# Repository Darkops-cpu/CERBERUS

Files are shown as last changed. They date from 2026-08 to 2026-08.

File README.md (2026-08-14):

# Cerberus

An open-source iCE40 FPGA development board with a fully open toolchain.

No licence server, no 100 GB install. Yosys, nextpnr and IceStorm run on any laptop and
synthesise a design this size in seconds.

> **Status:** rev A, first boards in fabrication. Untested. Do not fabricate your own copy
> until this note is gone.

---

## Features

| | |
|---|---|
| **FPGA** | Lattice iCE40UP5K — 5,280 LUT4, 120 kbit BRAM, 1 Mbit SPRAM, 8 DSP blocks |
| **PSRAM** | 8 MB QSPI (LY68L6400SLIT) |
| **Flash** | 4 MB SPI configuration flash (W25Q32) |
| **Host** | FT2232HL — USB programming *and* a serial console over one cable |
| **Clock** | 12 MHz active oscillator into a global clock buffer |
| **Expansion** | 2× PMOD, 8 user GPIO on a 0.1" header |
| **LEDs** | 3 user RGB + power, USB and CDONE status |
| **Connector** | USB-C |
| **PCB** | 4-layer, hand-assembled |

The FT2232H's two channels run independently, so you can flash a bitstream and watch a UART
console at the same time without switching modes.

---

## Getting started

### 1. Install the toolchain

Download the [OSS CAD Suite](https://github.com/YosysHQ/oss-cad-suite-build/releases) and
add it to your `PATH`. That's Yosys, nextpnr, IceStorm, Icarus, Verilator, GTKWave and
`iceprog` in one archive. Nothing to compile, nothing to licence.

```sh
source <path-to-oss-cad-suite>/environment
```

### 2. Build

```sh
yosys -p 'synth_ice40 -top top -json top.json' top.v
nextpnr-ice40 --up5k --package sg48 --json top.json --pcf cerberus.pcf --asc top.asc
icepack top.asc top.bin
```

### 3. Flash

The config SPI is on the FT2232H's **channel B**, so the `-I B` flag is required:

```sh
iceprog -I B top.bin
```

The CDONE LED lights when configuration succeeds.

### 4. Console

Channel A enumerates as a second serial port. On Linux the two channels appear as
`/dev/ttyUSB0` (A) and `/dev/ttyUSB1` (B):

```sh
picocom -b 115200 /dev/ttyUSB0
```

---

## Pinout

Key pins. Everything else is in `cerberus.pcf`.

| Function | FPGA pin |
|---|---|
| 12 MHz clock in | 37 (G1) |
| UART TX (FPGA → host) | 18 |
| UART RX (host → FPGA) | 19 |
| PSRAM CE# | 6 |
| PSRAM SCK | 9 |
| PSRAM SIO0–3 | 10, 11, 12, 13 |
| RGB LEDs | 39, 40, 41 |
| CDONE | 7 |
| CRESET_B | 8 |

Pins 14–17 are the configuration SPI bus and are not available to user designs.

**Globals available on this package:** 35 (G0), 37 (G1), 20 (G3), 44 (G6). Put clocks on
these — a clock on an ordinary pin routes through general fabric with worse skew.

**RGB LEDs** are constant-current sinks driven by the `SB_RGBA_DRV` primitive. Current is
set in the IP, not by a resistor.

---

## Notes

**Reset.** The button pulls `CRESET_B` low and reconfigures the FPGA from flash on release.
Configuration takes under 140 ms.

**Internal oscillator.** The iCE40's internal 48 MHz `SB_HFOSC` is ±20% on industrial parts.
Fine for blinking an LED, useless for a UART — that's why the board has an external
oscillator. Use pin 37.

**PSRAM.** The controller must break long transfers into chunks and deassert CE# between
them — the part self-refreshes only while CE# is high, and holding it low past the tCEM
window loses data. Linear burst across page boundaries is not supported on this part.

**Powering.** Bus-powered from USB-C. There is no barrel jack and no external supply input.

---

## Licence

Hardware: [CERN-OHL-S v2](https://cern-ohl.web.cern.ch/)
Gateware and examples: MIT

---

## Acknowledgements

Built on the work of [YosysHQ](https://github.com/YosysHQ) and
[Project IceStorm](https://github.com/YosysHQ/icestorm). Pin conventions follow
[iCEBreaker](https://github.com/icebreaker-fpga/icebreaker), and the SG48 pinout is
documented in Lattice FPGA-UG-02001.

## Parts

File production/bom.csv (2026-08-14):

Designator | Footprint | Quantity | Value | LCSC Part #
C1, C2, C3, C4 | 1210 | 4 | 100u
C10, C11, C12, C13, C14, C15, C16, C20, C21, C22, C23, C24, C25, C26, C27, C28, C30, C31, C5, C7, C8, C9 | 0603 | 22 | 100n
C17, C18 | 0603 | 2 | 12p
C19 | 0603 | 1 | 3.3u
C29, C32 | 0603 | 2 | 1u
C6 | 0603 | 1 | 10n
D1 | 0603 | 1 | Deep red 660 nm
D2 | 0603 | 1 | Amber 595 nm
D3 | 0805 | 1 | Warm white 3000 K
D4 | 0603 | 1 | Orange 610 nm
D5 | 0603 | 1 | Red 625 nm
D6 | 0603 | 1 | Yellow 585 nm
D7 | 0603 | 1 | Yellow-green 570 nm
F1, F2 | 0603 | 2 | Polyfuse
FB1, FB2, FB3, FB4, FB5, FB6 | 0603 | 6 | FerriteBead
IC1 | QFP50P1200X1200X160-64N | 1 | FT2232HL-REEL
J1 | USB_C_Receptacle_GCT_USB4105-xx-A_16P_TopMnt_Horizontal | 1 | USB_C_Receptacle_USB2.0_16P
J2 | PinHeader_1x06_P2.54mm_Vertical | 1 | Conn_01x06_Pin
J3 | PinHeader_1x13_P2.54mm_Horizontal | 1 | Conn_01x13_Pin
J4 | PinHeader_1x16_P2.54mm_Horizontal | 1 | Conn_01x16_Pin
R1, R2 | 0603 | 2 | 5k1
R10, R12, R13, R18, R19, R23 | 0603 | 6 | 10k
R11 | 0603 | 1 | 2k2
R14, R9 | 0603 | 2 | 1k
R15, R16, R7 | 0603 | 3 | 330
R17 | 0603 | 1 | 2k
R20, R21, R22, R4 | 0603 | 4 | 33
R3 | 0603 | 1 | 1k5
R5, R6 | 0603 | 2 | 100k
R8 | 0603 | 1 | 12k @1%
SW1 | SW_Push_SPST_NO_Alps_SKRK | 1 | SW_Push
TP1, TP2, TP3 | TestPoint_Pad_D1.5mm | 3 | TestPoint
U1 | APS6404L-3SQR-SN_APY | 1 | APS6404L-3SQR-SN
U2 | SOT-23-6 | 1 | LM3880
U3 | SOT-23-5 | 1 | TLV75512PDBV
U4 | SOT-23-5 | 1 | TLV75533PDBV
U5 | SOIC-8_3.9x4.9mm_P1.27mm | 1 | 93LCxxB
U6 | SOIC-8_5.3x5.3mm_P1.27mm | 1 | W25Q32JVSS
U8 | QFN-48-1EP_7x7mm_P0.5mm_EP5.6x5.6mm | 1 | ICE40UP5K-SG48ITR
Y2 | Oscillator_SMD_Abracon_ASV-4Pin_7.0x5.1mm | 1 | ASV-12MHz
Y3 | Crystal_SMD_3225-4Pin_3.2x2.5mm | 1 | 12mhz @ 10pf load

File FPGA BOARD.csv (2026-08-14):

Reference | Qty | Value | DNP | Exclude from BOM | Exclude from Board | Footprint | Datasheet
C1,C2,C3,C4 | 4 | 100u |  |  |  | Capacitor_SMD:C_0603_1608Metric_Pad1.08x0.95mm_HandSolder | ~
C5,C7,C8,C9,C10,C11,C12,C13,C14,C15,C16,C20,C21,C22,C23,C24,C25,C26,C27,C28,C30,C31 | 22 | 100n |  |  |  | Capacitor_SMD:C_0603_1608Metric_Pad1.08x0.95mm_HandSolder | ~
C6 | 1 | 10n |  |  |  | Capacitor_SMD:C_0603_1608Metric_Pad1.08x0.95mm_HandSolder | ~
C17,C18 | 2 | 32p |  |  |  | Capacitor_SMD:C_0603_1608Metric_Pad1.08x0.95mm_HandSolder | ~
C19 | 1 | 3.3u |  |  |  | Capacitor_SMD:C_0603_1608Metric_Pad1.08x0.95mm_HandSolder | ~
C29,C32 | 2 | 1u |  |  |  | Capacitor_SMD:C_0603_1608Metric_Pad1.08x0.95mm_HandSolder | ~
D1 | 1 | Deep red 660 nm |  |  |  | LED_SMD:LED_0603_1608Metric_Pad1.05x0.95mm_HandSolder | ~
D2 | 1 | Amber 595 nm |  |  |  | LED_SMD:LED_0603_1608Metric_Pad1.05x0.95mm_HandSolder | ~
D3 | 1 | Warm white 3000 K |  |  |  | LED_SMD:LED_0603_1608Metric_Pad1.05x0.95mm_HandSolder | ~
D4 | 1 | Orange 610 nm |  |  |  | LED_SMD:LED_0603_1608Metric_Pad1.05x0.95mm_HandSolder | ~
D5 | 1 | Red 625 nm |  |  |  | LED_SMD:LED_0603_1608Metric_Pad1.05x0.95mm_HandSolder | ~
D6 | 1 | Yellow 585 nm |  |  |  | LED_SMD:LED_0603_1608Metric_Pad1.05x0.95mm_HandSolder | ~
D7 | 1 | Yellow-green 570 nm |  |  |  | LED_SMD:LED_0603_1608Metric_Pad1.05x0.95mm_HandSolder | ~
F1,F2 | 2 | Polyfuse |  |  |  | Resistor_SMD:R_0603_1608Metric_Pad0.98x0.95mm_HandSolder | ~
FB1,FB2,FB3,FB4,FB5,FB6 | 6 | FerriteBead |  |  |  | Inductor_SMD:L_0603_1608Metric_Pad1.05x0.95mm_HandSolder | ~
H1,H2,H3,H4 | 4 | MountingHole_Pad |  | Excluded from BOM |  | MountingHole:MountingHole_2.2mm_M2_Pad_Via | ~
IC1 | 1 | FT2232HL-REEL |  |  |  | SamacSys_Parts:QFP50P1200X1200X160-64N | http://www.ftdichip.com/Support/Documents/DataSheets/ICs/DS_FT2232H.pdf
J1 | 1 | USB_C_Receptacle_USB2.0_16P |  |  |  | Connector_USB:USB_C_Receptacle_GCT_USB4105-xx-A_16P_TopMnt_Horizontal | https://www.usb.org/sites/default/files/documents/usb_type-c.zip
J2 | 1 | Conn_01x06_Pin |  |  |  | Connector_PinHeader_2.54mm:PinHeader_1x06_P2.54mm_Vertical | ~
J3 | 1 | Conn_01x13_Pin |  |  |  | Connector_PinHeader_2.54mm:PinHeader_1x13_P2.54mm_Horizontal | ~
J4 | 1 | Conn_01x16_Pin |  |  |  | Connector_PinHeader_2.54mm:PinHeader_1x16_P2.54mm_Horizontal | ~
R1,R2 | 2 | 5k1 |  |  |  | Resistor_SMD:R_0603_1608Metric_Pad0.98x0.95mm_HandSolder | ~
R3 | 1 | 1k5 |  |  |  | Resistor_SMD:R_0603_1608Metric_Pad0.98x0.95mm_HandSolder | ~
R4,R20,R21,R22 | 4 | 33 |  |  |  | Resistor_SMD:R_0603_1608Metric_Pad0.98x0.95mm_HandSolder | ~
R5,R6 | 2 | 100k |  |  |  | Resistor_SMD:R_0603_1608Metric_Pad0.98x0.95mm_HandSolder | ~
R7,R15,R16 | 3 | 330 |  |  |  | Resistor_SMD:R_0603_1608Metric_Pad0.98x0.95mm_HandSolder | ~
R8 | 1 | 12k @1% |  |  |  | Resistor_SMD:R_0603_1608Metric_Pad0.98x0.95mm_HandSolder | ~
R9,R14 | 2 | 1k |  |  |  | Resistor_SMD:R_0603_1608Metric_Pad0.98x0.95mm_HandSolder | ~
R10,R12,R13,R18,R19,R23 | 6 | 10k |  |  |  | Resistor_SMD:R_0603_1608Metric_Pad0.98x0.95mm_HandSolder | ~
R11 | 1 | 2k2 |  |  |  | Resistor_SMD:R_0603_1608Metric_Pad0.98x0.95mm_HandSolder | ~
R17 | 1 | 2k |  |  |  | Resistor_SMD:R_0603_1608Metric_Pad0.98x0.95mm_HandSolder | ~
SW1 | 1 | SW_Push |  |  |  | Button_Switch_SMD:SW_Push_SPST_NO_Alps_SKRK | ~
TP1,TP2,TP3 | 3 | TestPoint |  |  |  | TestPoint:TestPoint_Pad_D1.5mm | ~
U1 | 1 | APS6404L-3SQR-SN |  |  |  | APS6404L-3SQR-SN:APS6404L-3SQR-SN_APY | APS6404L-3SQR-SN
U2 | 1 | LM3880 |  |  |  | Package_TO_SOT_SMD:SOT-23-6 | http://www.ti.com/lit/ds/symlink/lm3880.pdf
U3 | 1 | TLV75512PDBV |  |  |  | Package_TO_SOT_SMD:SOT-23-5 | http://www.ti.com/lit/ds/symlink/tlv755p.pdf
U4 | 1 | TLV75533PDBV |  |  |  | Package_TO_SOT_SMD:SOT-23-5 | http://www.ti.com/lit/ds/symlink/tlv755p.pdf
U5 | 1 | 93LCxxB |  |  |  | Package_SO:SOIC-8_3.9x4.9mm_P1.27mm | http://ww1.microchip.com/downloads/en/DeviceDoc/20001749K.pdf
U6 | 1 | W25Q32JVSS |  |  |  | Package_SO:SOIC-8_5.3x5.3mm_P1.27mm | http://www.winbond.com/resource-files/w25q32jv%20revg%2003272018%20plus.pdf
U8 | 1 | ICE40UP5K-SG48ITR |  |  |  | Package_DFN_QFN:QFN-48-1EP_7x7mm_P0.5mm_EP5.6x5.6mm | http://www.latticesemi.com/Products/FPGAandCPLD/iCE40Ultra
Y2 | 1 | ASV-12MHz |  |  |  | Oscillator:Oscillator_SMD_Abracon_ASV-4Pin_7.0x5.1mm | http://www.abracon.com/Oscillators/ASV.pdf
Y3 | 1 | Crystal_GND24 |  |  |  | Crystal:Crystal_SMD_3225-4Pin_3.2x2.5mm | ~

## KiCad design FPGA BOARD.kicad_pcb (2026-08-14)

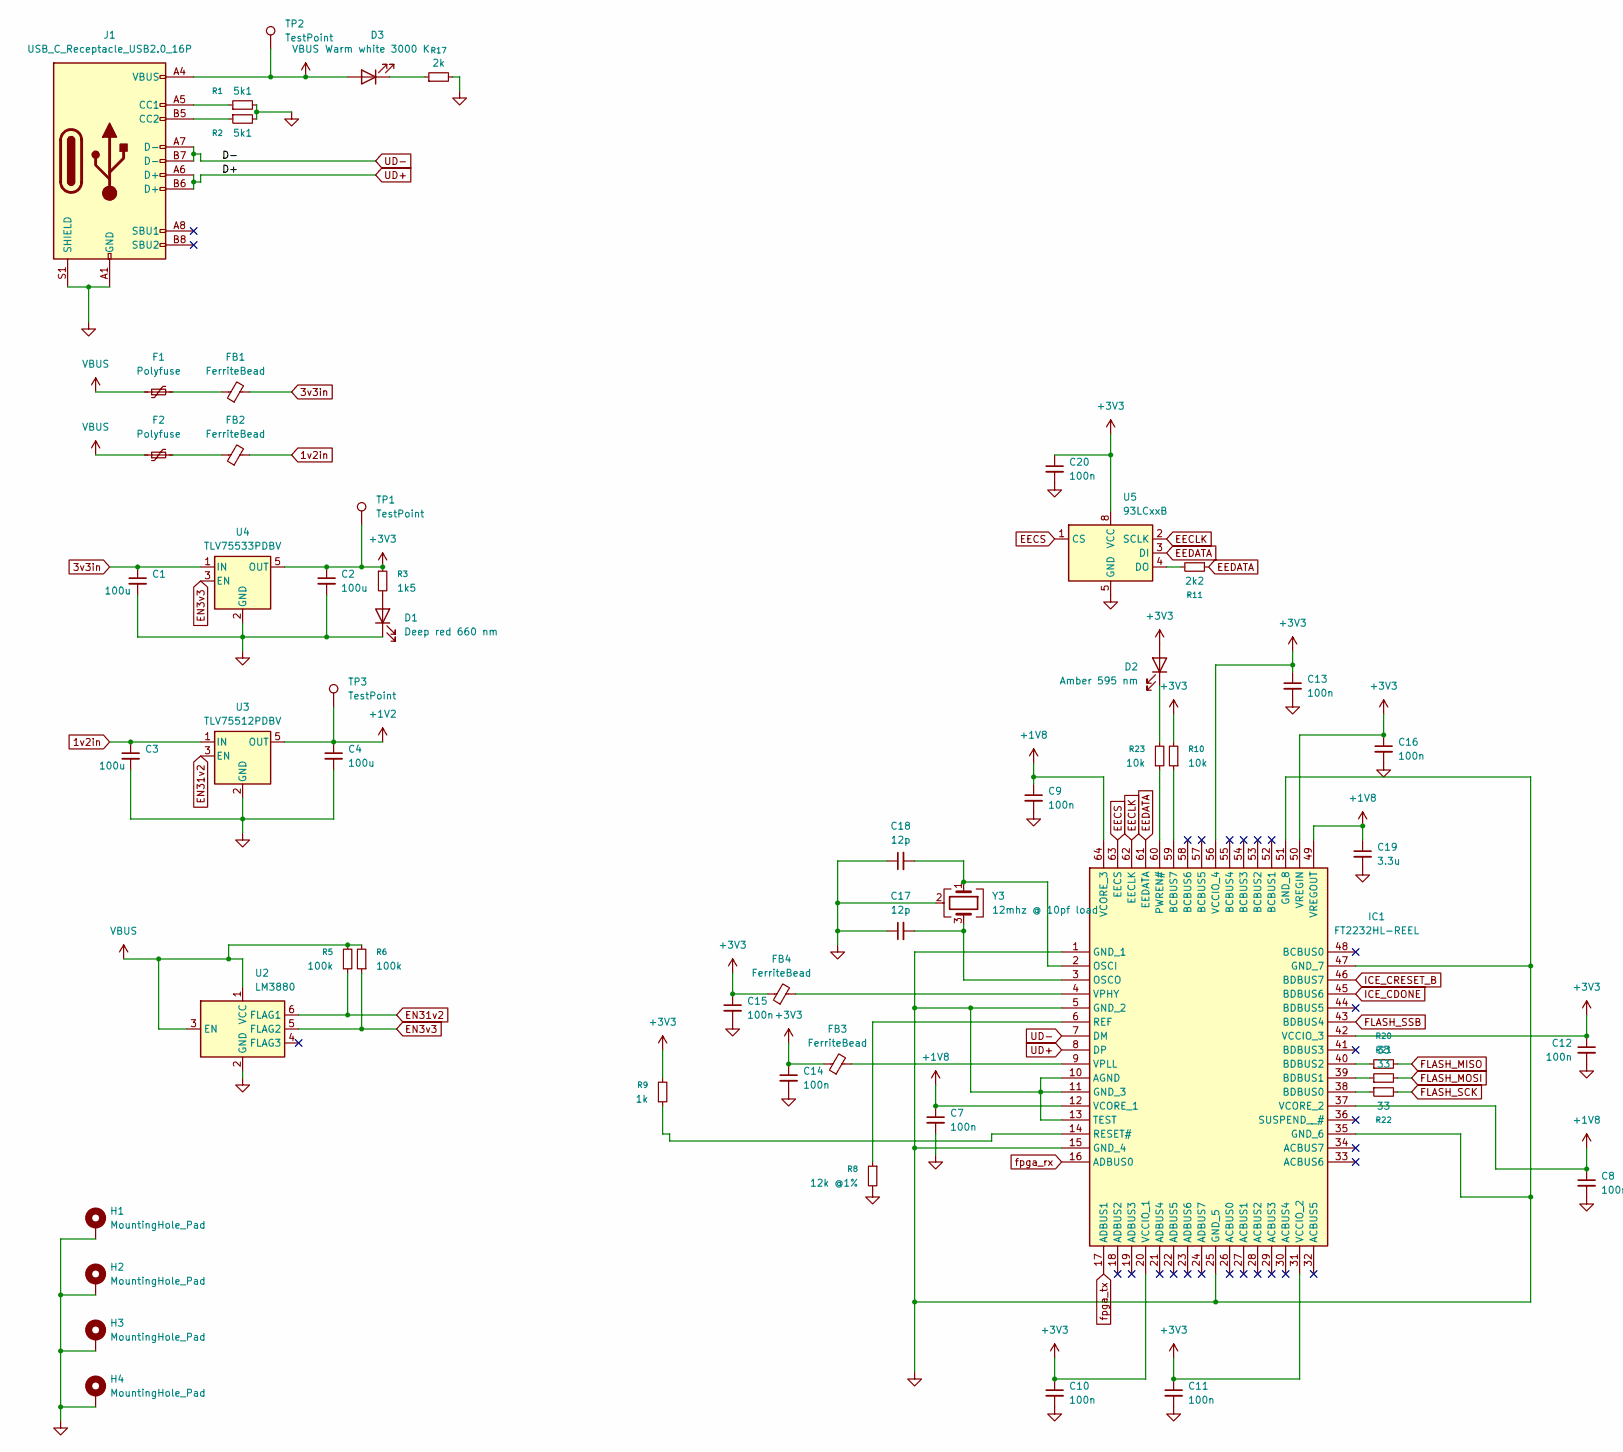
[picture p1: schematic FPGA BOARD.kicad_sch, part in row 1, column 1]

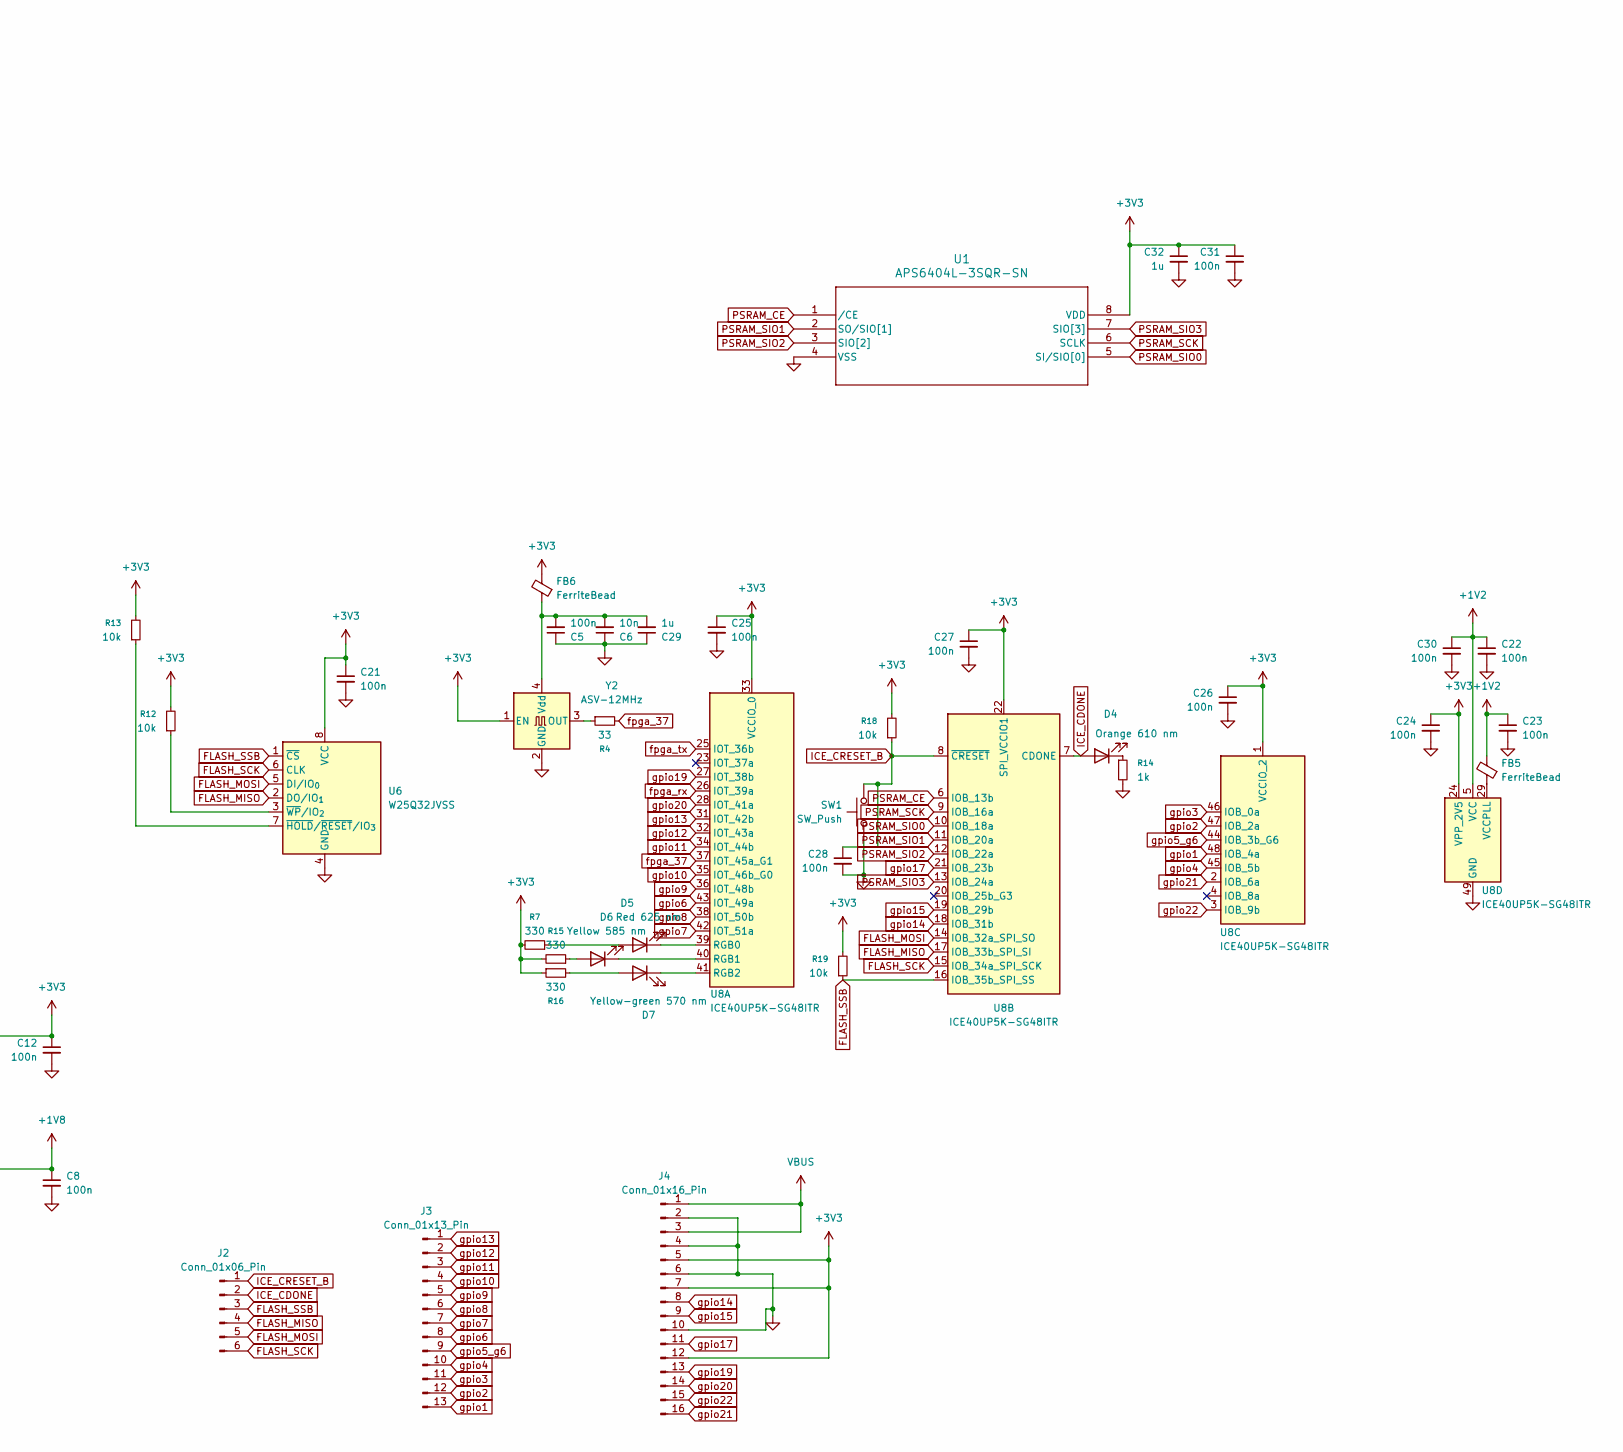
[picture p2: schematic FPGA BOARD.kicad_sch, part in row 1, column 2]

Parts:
C1, C2, C3, C4: 100u; C_1210_3225Metric_Pad1.33x2.70mm_HandSolder
C5, C7, C8, C9, C10, C11, C12, C13, C14, C15, C16, C20, C21, C22, C23, C24, C25, C26, C27, C28, C30, C31: 100n; C_0603_1608Metric_Pad1.08x0.95mm_HandSolder
C6: 10n; C_0603_1608Metric_Pad1.08x0.95mm_HandSolder
C17, C18: 12p; C_0603_1608Metric_Pad1.08x0.95mm_HandSolder
C19: 3.3u; C_0603_1608Metric_Pad1.08x0.95mm_HandSolder
C29, C32: 1u; C_0603_1608Metric_Pad1.08x0.95mm_HandSolder
D1: Deep red 660 nm; LED_0603_1608Metric_Pad1.05x0.95mm_HandSolder
D2: Amber 595 nm; LED_0603_1608Metric_Pad1.05x0.95mm_HandSolder
D3: Warm white 3000 K; LED_0805_2012Metric_Pad1.15x1.40mm_HandSolder
D4: Orange 610 nm; LED_0603_1608Metric_Pad1.05x0.95mm_HandSolder
D5: Red 625 nm; LED_0603_1608Metric_Pad1.05x0.95mm_HandSolder
D6: Yellow 585 nm; LED_0603_1608Metric_Pad1.05x0.95mm_HandSolder
D7: Yellow-green 570 nm; LED_0603_1608Metric_Pad1.05x0.95mm_HandSolder
F1, F2: Polyfuse; R_0603_1608Metric_Pad0.98x0.95mm_HandSolder
FB1, FB2, FB3, FB4, FB5, FB6: FerriteBead; L_0603_1608Metric_Pad1.05x0.95mm_HandSolder
H1, H2, H3, H4: MountingHole_Pad; MountingHole_2.2mm_M2_Pad_Via
IC1: FT2232HL-REEL; QFP50P1200X1200X160-64N; Mouser Part Number 895-FT2232HL
J1: USB_C_Receptacle_USB2.0_16P; USB_C_Receptacle_GCT_USB4105-xx-A_16P_TopMnt_Horizontal
J2: Conn_01x06_Pin; PinHeader_1x06_P2.54mm_Vertical
J3: Conn_01x13_Pin; PinHeader_1x13_P2.54mm_Horizontal
J4: Conn_01x16_Pin; PinHeader_1x16_P2.54mm_Horizontal
R1, R2: 5k1; R_0603_1608Metric_Pad0.98x0.95mm_HandSolder
R3: 1k5; R_0603_1608Metric_Pad0.98x0.95mm_HandSolder
R4, R20, R21, R22: 33; R_0603_1608Metric_Pad0.98x0.95mm_HandSolder
R5, R6: 100k; R_0603_1608Metric_Pad0.98x0.95mm_HandSolder
R7, R15, R16: 330; R_0603_1608Metric_Pad0.98x0.95mm_HandSolder
R8: 12k @1%; R_0603_1608Metric_Pad0.98x0.95mm_HandSolder
R9, R14: 1k; R_0603_1608Metric_Pad0.98x0.95mm_HandSolder
R10, R12, R13, R18, R19, R23: 10k; R_0603_1608Metric_Pad0.98x0.95mm_HandSolder
R11: 2k2; R_0603_1608Metric_Pad0.98x0.95mm_HandSolder
R17: 2k; R_0603_1608Metric_Pad0.98x0.95mm_HandSolder
SW1: SW_Push; SW_Push_SPST_NO_Alps_SKRK
TP1, TP2, TP3: TestPoint; TestPoint_Pad_D1.5mm
U1: APS6404L-3SQR-SN; APS6404L-3SQR-SN_APY
U2: LM3880; SOT-23-6
U3: TLV75512PDBV; SOT-23-5
U4: TLV75533PDBV; SOT-23-5
U5: 93LCxxB; SOIC-8_3.9x4.9mm_P1.27mm
U6: W25Q32JVSS; SOIC-8_5.3x5.3mm_P1.27mm
U8: ICE40UP5K-SG48ITR; QFN-48-1EP_7x7mm_P0.5mm_EP5.6x5.6mm
Y2: ASV-12MHz; Oscillator_SMD_Abracon_ASV-4Pin_7.0x5.1mm
Y3: 12mhz @ 10pf load; Crystal_SMD_3225-4Pin_3.2x2.5mm

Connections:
1v2in: C3.1, FB2.2, U3.1 (IN)
3v3in: C1.1, FB1.2, U4.1 (IN)
+1V2: C4.1, C22.1, C23.1, C30.1, FB5.2, TP3.1, U3.5 (OUT), U8.5 (VCC), U8.30 (VCC)
+1V8: C7.1, C8.1, C9.1, C19.1, IC1.12 (VCORE_1), IC1.37 (VCORE_2), IC1.49 (VREGOUT), IC1.64 (VCORE_3)
+3V3: C2.1, C10.1, C11.1, C12.1, C13.1, C14.1, C15.1, C16.1, C20.1, C21.1, C24.1, C25.1, C26.1, C27.1, C31.1, C32.1, D2.2 (A), FB3.1, FB4.1, FB6.2, IC1.20 (VCCIO_1), IC1.31 (VCCIO_2), IC1.42 (VCCIO_3), IC1.50 (VREGIN), IC1.56 (VCCIO_4), J4.5, J4.7, J4.12, R3.1, R7.2, R9.2, R10.2, R12.2, R13.2, R15.2, R16.1, R18.2, R19.2, TP1.1, U1.8 (VDD), U4.5 (OUT), U5.8 (VCC), U6.8 (VCC), U8.1 (VCCIO_2), U8.22 (SPI_VCCIO1), U8.24 (VPP_2V5), U8.33 (VCCIO_0), Y2.1 (EN)
EECLK: IC1.62 (EECLK), U5.2 (SCLK)
EECS: IC1.63 (EECS), U5.1 (CS)
EEDATA: IC1.61 (EEDATA), R11.1, U5.3 (DI)
EN3v3: R6.1, U2.5 (FLAG2), U4.3 (EN)
EN31v2: R5.1, U2.6 (FLAG1), U3.3 (EN)
FLASH_MISO: J2.4, R20.2, U6.2 (DO/IO_{1}), U8.17 (IOB_33b_SPI_SI)
FLASH_MOSI: J2.5, R21.2, U6.5 (DI/IO_{0}), U8.14 (IOB_32a_SPI_SO)
FLASH_SCK: J2.6, R22.2, U6.6 (CLK), U8.15 (IOB_34a_SPI_SCK)
FLASH_SSB: IC1.43 (BDBUS4), J2.3, R19.1, U6.1 (~CS), U8.16 (IOB_35b_SPI_SS)
GND: C1.2, C2.2, C3.2, C4.2, C5.1, C6.1, C7.2, C8.2, C9.2, C10.2, C11.2, C12.2, C13.2, C14.2, C15.2, C16.2, C17.1, C18.1, C19.2, C20.2, C21.2, C22.2, C23.2, C24.2, C25.2, C26.2, C27.2, C28.2, C29.1, C30.2, C31.2, C32.2, D1.1 (K), H1.1, H2.1, H3.1, H4.1, IC1.1 (GND_1), IC1.5 (GND_2), IC1.10 (AGND), IC1.11 (GND_3), IC1.13 (TEST), IC1.15 (GND_4), IC1.25 (GND_5), IC1.35 (GND_6), IC1.47 (GND_7), IC1.51 (GND_8), J1.A1 (GND), J1.A12 (GND), J1.B1 (GND), J1.B12 (GND), J1.S1 (SHIELD), J4.2, J4.4, J4.6, J4.10, R1.2, R2.2, R8.2, R14.2, R17.2, SW1.1, U1.4 (VSS), U2.2 (GND), U3.2 (GND), U4.2 (GND), U5.5 (GND), U6.4 (GND), U8.49 (GND), Y2.2 (GND), Y3.2 (G), Y3.4 (G)
ICE_CDONE: D4.2 (A), IC1.45 (BDBUS6), J2.2, U8.7 (CDONE)
ICE_CRESET_B: C28.1, IC1.46 (BDBUS7), J2.1, R18.1, SW1.2, U8.8 (~CRESET)
unnamed: D1.2 (A), R3.2
unnamed: D2.1 (K), R23.2
unnamed: D3.1 (K), R17.1
unnamed: D4.1 (K), R14.1
unnamed: D5.2 (A), R7.1
unnamed: D5.1 (K), U8.39 (RGB0)
unnamed: D6.2 (A), R15.1
unnamed: D6.1 (K), U8.40 (RGB1)
unnamed: D7.2 (A), R16.2
unnamed: D7.1 (K), U8.41 (RGB2)
unnamed: F1.2, FB1.1
unnamed: F2.2, FB2.1
unnamed: IC1.59 (BCBUS7), R10.1
unnamed: IC1.38 (BDBUS0), R22.1
unnamed: IC1.39 (BDBUS1), R21.1
unnamed: IC1.40 (BDBUS2), R20.1
unnamed: C18.2, IC1.2 (OSCI), Y3.1
unnamed: C17.2, IC1.3 (OSCO), Y3.3
unnamed: IC1.60 (PWREN#), R23.1
unnamed: IC1.6 (REF), R8.1
unnamed: IC1.14 (RESET#), R9.1
unnamed: FB4.2, IC1.4 (VPHY)
unnamed: FB3.2, IC1.9 (VPLL)
unnamed: J1.A5 (CC1), R1.1
unnamed: J1.B5 (CC2), R2.1
unnamed: R11.2, U5.4 (DO)
unnamed: R13.1, U6.7 (~HOLD/~RESET/IO_{3})
unnamed: R12.1, U6.3 (~WP/IO_{2})
unnamed: FB5.1, U8.29 (VCCPLL)
unnamed: R4.1, Y2.3 (OUT)
unnamed: C5.2, C6.2, C29.2, FB6.1, Y2.4 (Vdd)
PSRAM_CE: U1.1 (/CE), U8.6 (IOB_13b)
PSRAM_SCK: U1.6 (SCLK), U8.9 (IOB_16a)
PSRAM_SIO0: U1.5 (SI/SIO[0]), U8.10 (IOB_18a)
PSRAM_SIO1: U1.2 (SO/SIO[1]), U8.11 (IOB_20a)
PSRAM_SIO2: U1.3 (SIO[2]), U8.12 (IOB_22a)
PSRAM_SIO3: U1.7 (SIO[3]), U8.13 (IOB_24a)
UD+: IC1.8 (DP), J1.A6 (D+), J1.B6 (D+)
UD-: IC1.7 (DM), J1.A7 (D-), J1.B7 (D-)
VBUS: D3.2 (A), F1.1, F2.1, J1.A4 (VBUS), J1.A9 (VBUS), J1.B4 (VBUS), J1.B9 (VBUS), J4.1, J4.3, R5.2, R6.2, TP2.1, U2.1 (VCC), U2.3 (EN)
fpga_37: R4.2, U8.37 (IOT_45a_G1)
fpga_rx: IC1.16 (ADBUS0), U8.26 (IOT_39a)
fpga_tx: IC1.17 (ADBUS1), U8.25 (IOT_36b)
gpio1: J3.13, U8.48 (IOB_4a)
gpio2: J3.12, U8.47 (IOB_2a)
gpio3: J3.11, U8.46 (IOB_0a)
gpio4: J3.10, U8.45 (IOB_5b)
gpio5_g6: J3.9, U8.44 (IOB_3b_G6)
gpio6: J3.8, U8.43 (IOT_49a)
gpio7: J3.7, U8.42 (IOT_51a)
gpio8: J3.6, U8.38 (IOT_50b)
gpio9: J3.5, U8.36 (IOT_48b)
gpio10: J3.4, U8.35 (IOT_46b_G0)
gpio11: J3.3, U8.34 (IOT_44b)
gpio12: J3.2, U8.32 (IOT_43a)
gpio13: J3.1, U8.31 (IOT_42b)
gpio14: J4.8, U8.18 (IOB_31b)
gpio15: J4.9, U8.19 (IOB_29b)
gpio17: J4.11, U8.21 (IOB_23b)
gpio19: J4.13, U8.27 (IOT_38b)
gpio20: J4.14, U8.28 (IOT_41a)
gpio21: J4.16, U8.2 (IOB_6a)
gpio22: J4.15, U8.3 (IOB_9b)

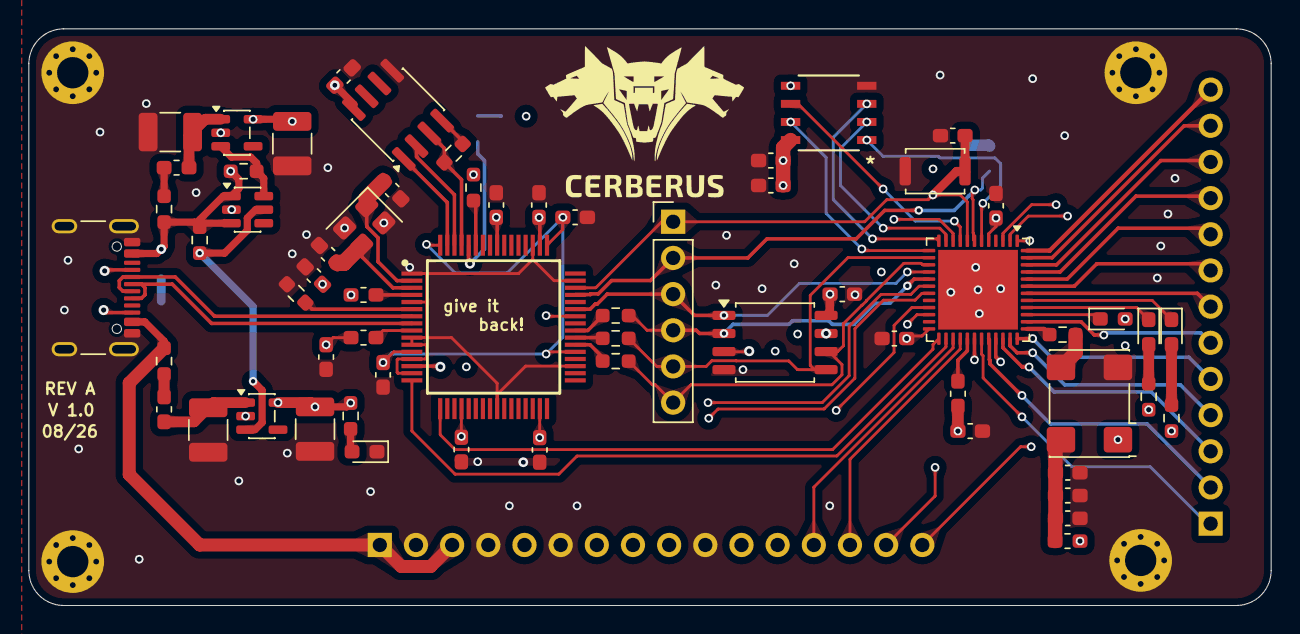
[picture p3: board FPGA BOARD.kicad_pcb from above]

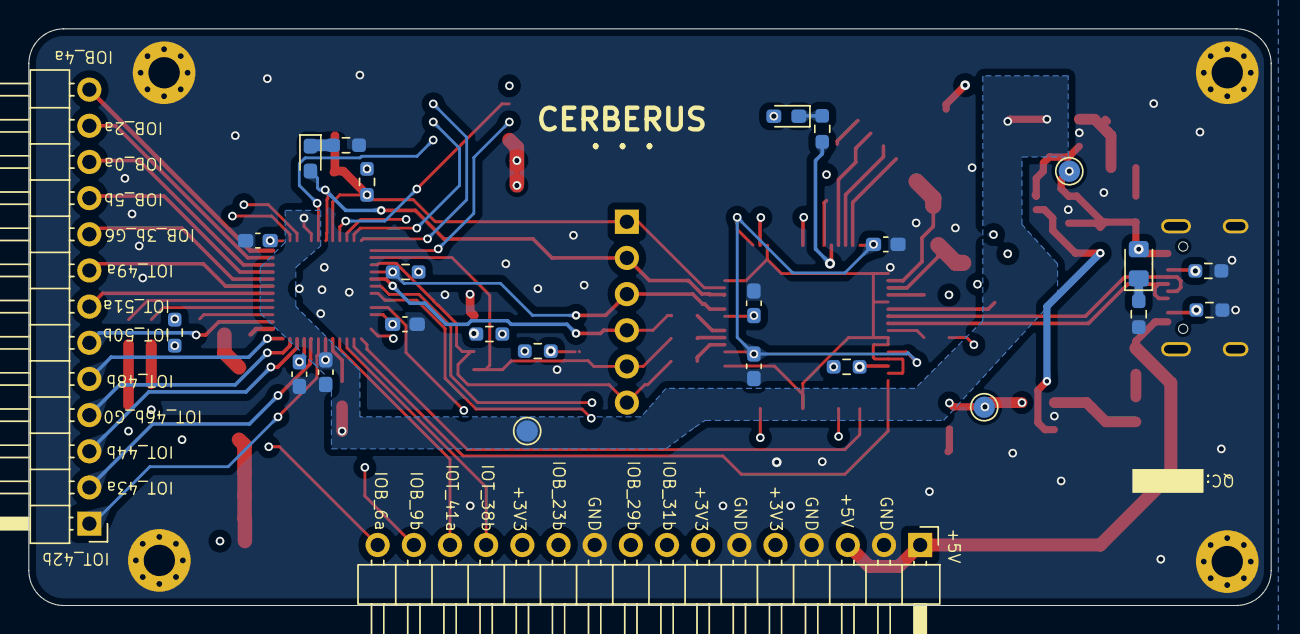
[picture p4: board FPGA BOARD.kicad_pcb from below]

Board: 4 copper layers, 87.2 x 40.5 mm, 92 parts (26 on the bottom side), 80 nets.
